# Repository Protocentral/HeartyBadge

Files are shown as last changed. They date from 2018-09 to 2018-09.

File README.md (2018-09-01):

# ProtoCentral HeartyBadge

HeartyBadge is simply our popular HeartyPatch single-lead ECG & Heart-rate variability (HRV) monitoring device made into a badge in time for DEFCON 26, where I presented about our HealthyPi open-source patient monitor. We think of HeartyBadge as a ECG and HRV development board, on a badge. 

The following are the main features of the HeartyBadge: 
* Single-lead ECG monitoring with the MAX30003 
* 2 gold-plated pads on the PCB act as electrodes 
* ESP32 with PCB antenna supporting Bluetooth & Wi-Fi 
* 144 APA102 RGB addressable LEDs (most of them in a matrix) 
* On-board Li-Ion battery with charging 
* USB for charging, code upload as well as debugging 

More information is available on our Hackaday project page at: https://hackaday.io/project/160846-heartybadge

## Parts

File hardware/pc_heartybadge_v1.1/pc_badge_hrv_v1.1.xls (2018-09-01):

pc_badge_hrv_v1.1
Qty | Value | Parts | Package
5 | 0.1uF | C2, C6, C7, C8, C11 | C0402
2 | 0.1uF | C60, C62 | C0402
1 | 1.0uF | C63 | C0402
1 | 1000pF | C76 | C0402
2 | 100nF | C81, C82 | _0402
84 |  | C1, C3, C4, C5, C9, C10, C12, C14, C16, C17, C18, C19, C21, C22, C23, C24, C25, C26, C27, C28, C29, C30, C31, C32, C33, C34, C35, C36, C37, C38, C39, C40, C41, C42, C43, C44, C45, C46, C47, C50, C51, C52, C53, C54, C55, C56, C59, C66, C83, C84, C85, C86, C87, C88, C89, C90, C91, C92, C93, C94, C95, C96, C97, C98, C99, C100, C101, C102, C103, C104, C105, C106, C107, C108, C109, C110, C111, C112, C113, C114, C115, C116, C117, C118 | C0402K
2 | 10pF | C74, C75 | C0402
2 | 10uF | C13, C15 | C0603
6 | 10uF | C70, C71, C77, C79, C121, C122 | C0402
1 | 10uF | C61 | C0805
2 | 15pF | C57, C58 | C0603
1 | 1nF | C68 | C0402
3 | 1u | C72, C119, C120 | C0402
4 | 1uF | C20, C69, C73, C78 | C0402
1 | 1uF | C80 | C0402
1 | 2.2uF | C67 | C0402
1 | 2.4pF | C48 | C0603
2 | 4.7u | C64, C65 | C0805
1 | 5.6pF | C49 | C0603
2 | 10K | R19, R23 | R0402
3 | 10K | R1, R4, R7 | 0402-RES
2 | 10k | R9, R10 | R0603
4 | 10k | R8, R11, R25, R26 | R0603
1 | 10k | R20 | R0402
2 | 1K | R12, R13 | R0402
1 | 1k | R17 | R0402
2 | 27R | R14, R15 | R0402
3 | 330R | R2, R5, R16 | R0402
2 | 49.9K | R3, R6 | 0402-RES
1 | 2.5A/30V | Q2 | SOT23-3
1 | 2.7nH | L1 | L0603
1 | 32.768kHz | Y1 | CRYSTAL-SMD-3.2X1.5MM
1 | AP2112K-1.8V | U9 | SOT23-5
1 | AP2112K-3.3V | U8 | SOT23-5
1 | AP2281 | U$2 | SOT26
117 | APA1022020 | U$9, U$10, U$11, U$12, U$13, U$14, U$15, U$18, U$19, U$20, U$21, U$22, U$24, U$25, U$27, U$28, U$29, U$30, U$31, U$32, U$33, U$34, U$35, U$36, U$37, U$38, U$39, U$40, U$41, U$42, U$43, U$44, U$45, U$46, U$47, U$48, U$49, U$50, U$51, U$52, U$53, U$54, U$55, U$56, U$57, U$58, U$59, U$60, U$61, U$62, U$63, U$64, U$65, U$66, U$67, U$68, U$69, U$70, U$71, U$72, U$73, U$74, U$75, U$76, U$77, U$78, U$79, U$80, U$81, U$82, U$83, U$84, U$85, U$86, U$87, U$88, U$89, U$90, U$91, U$92, U$93, U$94, U$95, U$96, U$97, U$98, U$99, U$100, U$101, U$102, U$103, U$104, U$106, U$107, U$108, U$109, U$110, U$111, U$112, U$113, U$114, U$115, U$116, U$117, U$118, U$119, U$120, U$121, U$122, U$123, U$124, U$125, U$126, U$127, U$128, U$129, U$130 | APA102_2020
1 | BAT20J | D1 | SOD-323
1 | CY8C29666_QFN48 | IC1 | QFN48
1 | DNP | R18 | R0402
1 | FTS31XS-U | U1 | SSOP20_L
1 | KMR2 | SW2 | BTN_KMR2_4.6X2.8
1 | LSM6DS3 | U2 | LGA14L
1 | MAX30003CTI+ | U$131 | QFN-28
1 | MBT3904DW1T1 | Q1 | SC70-6
1 | MCP73831 | U3 | SOT23-5
1 | MICRO-B | JP7 | MICRO-B
1 | PCM12SMTR | S2 | SWITCH-SPST-SMD-A
1 | RED | CHG2 | CHIPLED_0603
1 | SIT1533 | U$134 | SIT1533

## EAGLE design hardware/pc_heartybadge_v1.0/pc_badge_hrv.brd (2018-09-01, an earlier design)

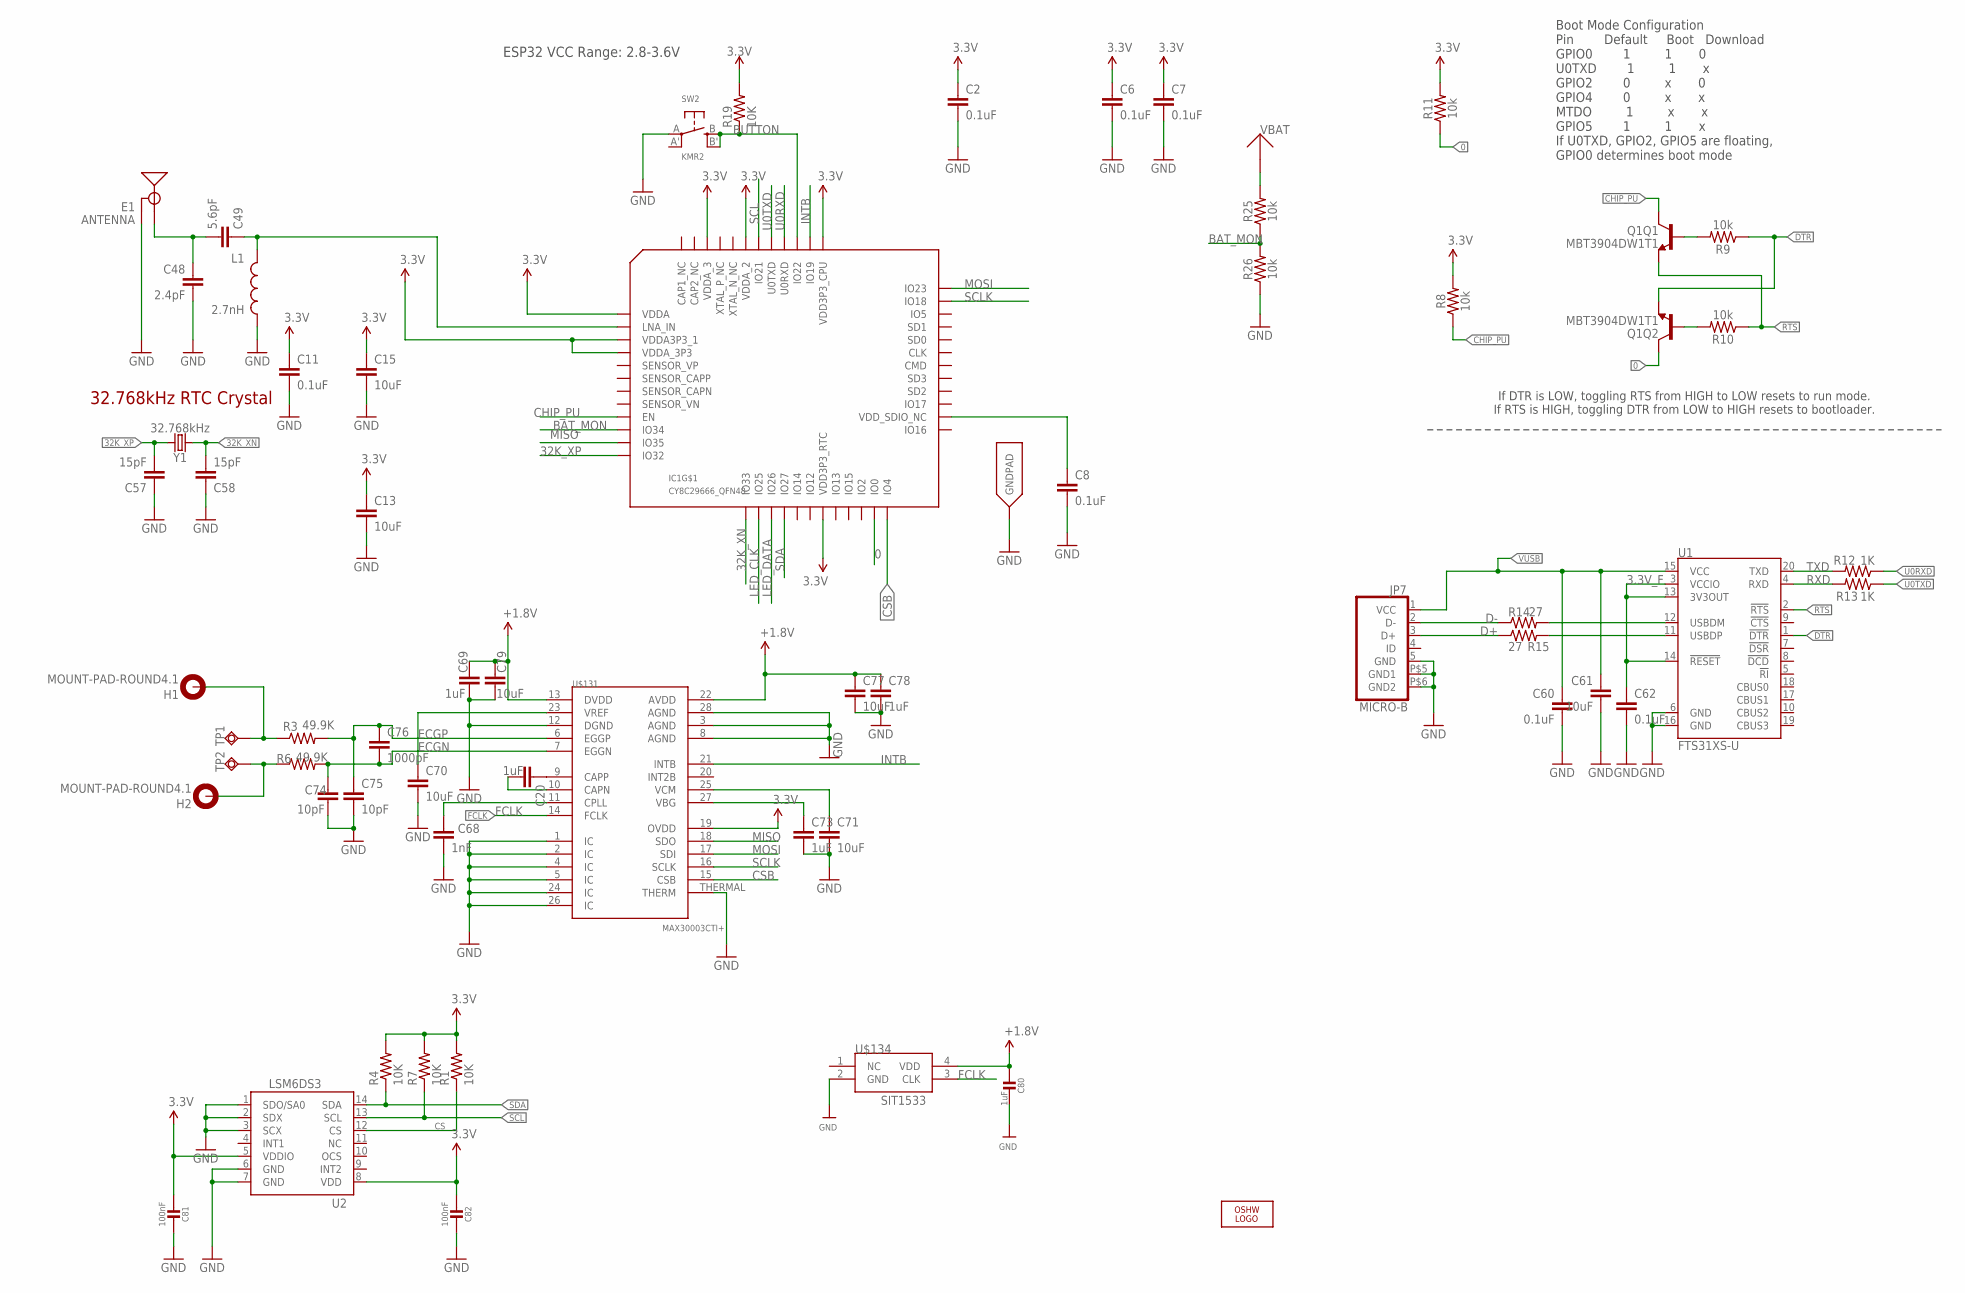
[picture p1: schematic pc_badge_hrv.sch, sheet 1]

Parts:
C2, C6, C7, C8, C11: 0.1uF; 0402
C13, C15: 10uF; 0603
C20, C69, C73, C78: 1uF; C0402
C48: 2.4pF; 0603
C49: 5.6pF; 0603
C57, C58: 15pF; 0603
C60, C62: 0.1uF; C0402
C61: 10uF; C0805
C68: 1nF; C0402
C70, C71, C77, C79: 10uF; C0402
C74, C75: 10pF; C0402
C76: 1000pF; C0402
C80: 1uF; _0402
C81, C82: 100nF; _0402
E1: ANTENNA; TRACE_ANTENNA_2.4GHZ_25.7MM_TUNED
H1, H2: MOUNT-PAD-ROUND4.1; 4,1-PAD
IC1: CY8C29666_QFN48; QFN48
JP7: MICRO-B
L1: 2.7nH; 0603
LOGO3: OSHW_LOGO_FILLX0200-NT; OSHW_FILLX200_NOTEXT
Q1: MBT3904DW1T1; SC70-6
R1, R4, R7: 10K; 0402-RES
R3, R6: 49.9K; 0402-RES
R8, R9, R10, R11, R25, R26: 10k; 0603
R12, R13: 1K; R0402
R14, R15: 27; R0402
R19: 10K; R0402
SW2: KMR2; BTN_KMR2_4.6X2.8
TP1, TP2: TPSQTP11R; TP11R
U1: FTS31XS-U; SSOP20_L
U2: LSM6DS3; LGA14L
U$131: MAX30003CTI+; QFN-28
U$134: SIT1533
Y1: 32.768kHz; CRYSTAL-SMD-3.2X1.5MM

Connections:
0: IC1.23 (IO0), Q1.6 (C), R11.1
3.3V: C2.1, C6.1, C7.1, C11.1, C13.1, C15.1, C81.1, C82.1, IC1.1 (VDDA), IC1.3 (VDDA3P3_1), IC1.4 (VDDA_3P3), IC1.19 (VDD3P3_RTC), IC1.37 (VDD3P3_CPU), IC1.43 (VDDA_2), IC1.46 (VDDA_3), R1.2, R4.2, R7.2, R8.2, R11.2, R19.2, U2.5 (VDDIO), U2.8 (VDD), U$131.19 (OVDD); also elsewhere on the board
3.3V_F: C62.1, U1.3 (VCCIO), U1.13 (3V3OUT), U1.14 (!RESET)
32K_XN: C58.2, IC1.13 (IO33), Y1.P$2 (2)
32K_XP: C57.2, IC1.12 (IO32), Y1.P$1 (1)
+1.8V: C69.1, C77.1, C78.1, C79.1, C80.1, U$131.13 (DVDD), U$131.22 (AVDD), U$134.4 (VDD)
BAT_MON: IC1.10 (IO34), R25.1, R26.2
BUTTON: IC1.39 (IO22), R19.1, SW2.B (S), SW2.B' (S1)
CHIP_PU: IC1.9 (EN), Q1.3 (C), R8.1
CS: R1.1, U2.12 (CS)
CSB: IC1.24 (IO4), U$131.15 (CSB)
D+: JP7.3 (D+), R15.1
D-: JP7.2 (D-), R14.1
DTR: Q1.1 (E), R9.1, U1.1 (!DTR)
ECGN: C74.1, C76.2, R6.2, U$131.7 (EGGN)
ECGP: C75.1, C76.1, R3.2, U$131.6 (EGGP)
ECG_N: H2.B4,1, R6.1, TP2.TP
ECG_P: H1.B4,1, R3.1, TP1.TP
FCLK: U$131.14 (FCLK), U$134.3 (CLK)
GND: C2.2, C6.2, C7.2, C8.2, C11.2, C13.2, C15.2, C48.2, C57.1, C58.1, C60.2, C61.2, C62.2, C68.2, C69.2, C70.2, C71.2, C73.2, C74.2, C75.2, C77.2, C78.2, C79.2, C80.2, C81.2, C82.2, E1.GND, E1.GND2 (GND), IC1.EXP (GNDPAD), JP7.5 (GND), JP7.P$5 (GND1), JP7.P$6 (GND2), L1.2, R26.1, SW2.A, U1.6 (GND), U1.16 (GND), U2.1 (SDO/SA0), U2.2 (SDX), U2.3 (SCX), U2.6 (GND), U2.7 (GND), U$131.1 (IC), U$131.2 (IC), U$131.3 (AGND), U$131.4 (IC), U$131.5 (IC), U$131.8 (AGND), U$131.12 (DGND), U$131.24 (IC), U$131.26 (IC), U$131.28 (AGND), U$131.THERMAL (THERM), U$134.2 (GND); also elsewhere on the board
INTB: IC1.38 (IO19), U$131.21 (INTB)
IO12: IC1.18 (IO12)
LED_CLK: IC1.14 (IO25); also elsewhere on the board
LED_DATA: IC1.15 (IO26); also elsewhere on the board
LNA_IN: C49.1, IC1.2 (LNA_IN), L1.1
MISO: IC1.11 (IO35), U$131.18 (SDO)
MOSI: IC1.36 (IO23), U$131.17 (SDI)
unnamed: C8.1, IC1.26 (VDD_SDIO_NC)
unnamed: Q1.5 (B), R9.2
unnamed: Q1.2 (B), R10.2
unnamed: R14.2, U1.12 (USBDM)
unnamed: R15.2, U1.11 (USBDP)
unnamed: C68.1, U$131.11 (CPLL)
unnamed: C20.1, U$131.9 (CAPP)
unnamed: C20.2, U$131.10 (CAPN)
unnamed: C70.1, U$131.23 (VREF)
unnamed: C71.1, U$131.25 (VCM)
unnamed: C73.1, U$131.27 (VBG)
RTS: Q1.4 (E), R10.1, U1.2 (!RTS)
RXD: R13.2, U1.4 (RXD)
SCL: IC1.42 (IO21), R7.1, U2.13 (SCL)
SCLK: IC1.35 (IO18), U$131.16 (SCLK)
SDA: IC1.16 (IO27), R4.1, U2.14 (SDA)
SENSOR_CAPN: IC1.7 (SENSOR_CAPN)
TRACE_ANT2: C48.1, C49.2, E1.ANT (SIGNAL)
TXD: R12.2, U1.20 (TXD)
U0RXD: IC1.40 (U0RXD), R12.1
U0TXD: IC1.41 (U0TXD), R13.1
VBAT: R25.2; also elsewhere on the board
VUSB: C60.1, C61.1, JP7.1 (VCC), U1.15 (VCC); also elsewhere on the board

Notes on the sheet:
Boot Mode Configuration Pin Default Boot Download GPIO0 1 1 0 U0TXD 1 1 x GPIO2 0 x 0 GPIO4 0 x x MTDO 1 x x GPIO5 1 1 x If U0TXD, GPIO2, GPIO5 are floating, GPIO0 determines boot mode
32.768kHz RTC Crystal
ESP32 VCC Range: 2.8-3.6V
If DTR is LOW, toggling RTS from HIGH to LOW resets to run mode. If RTS is HIGH, toggling DTR from LOW to HIGH resets to bootloader.

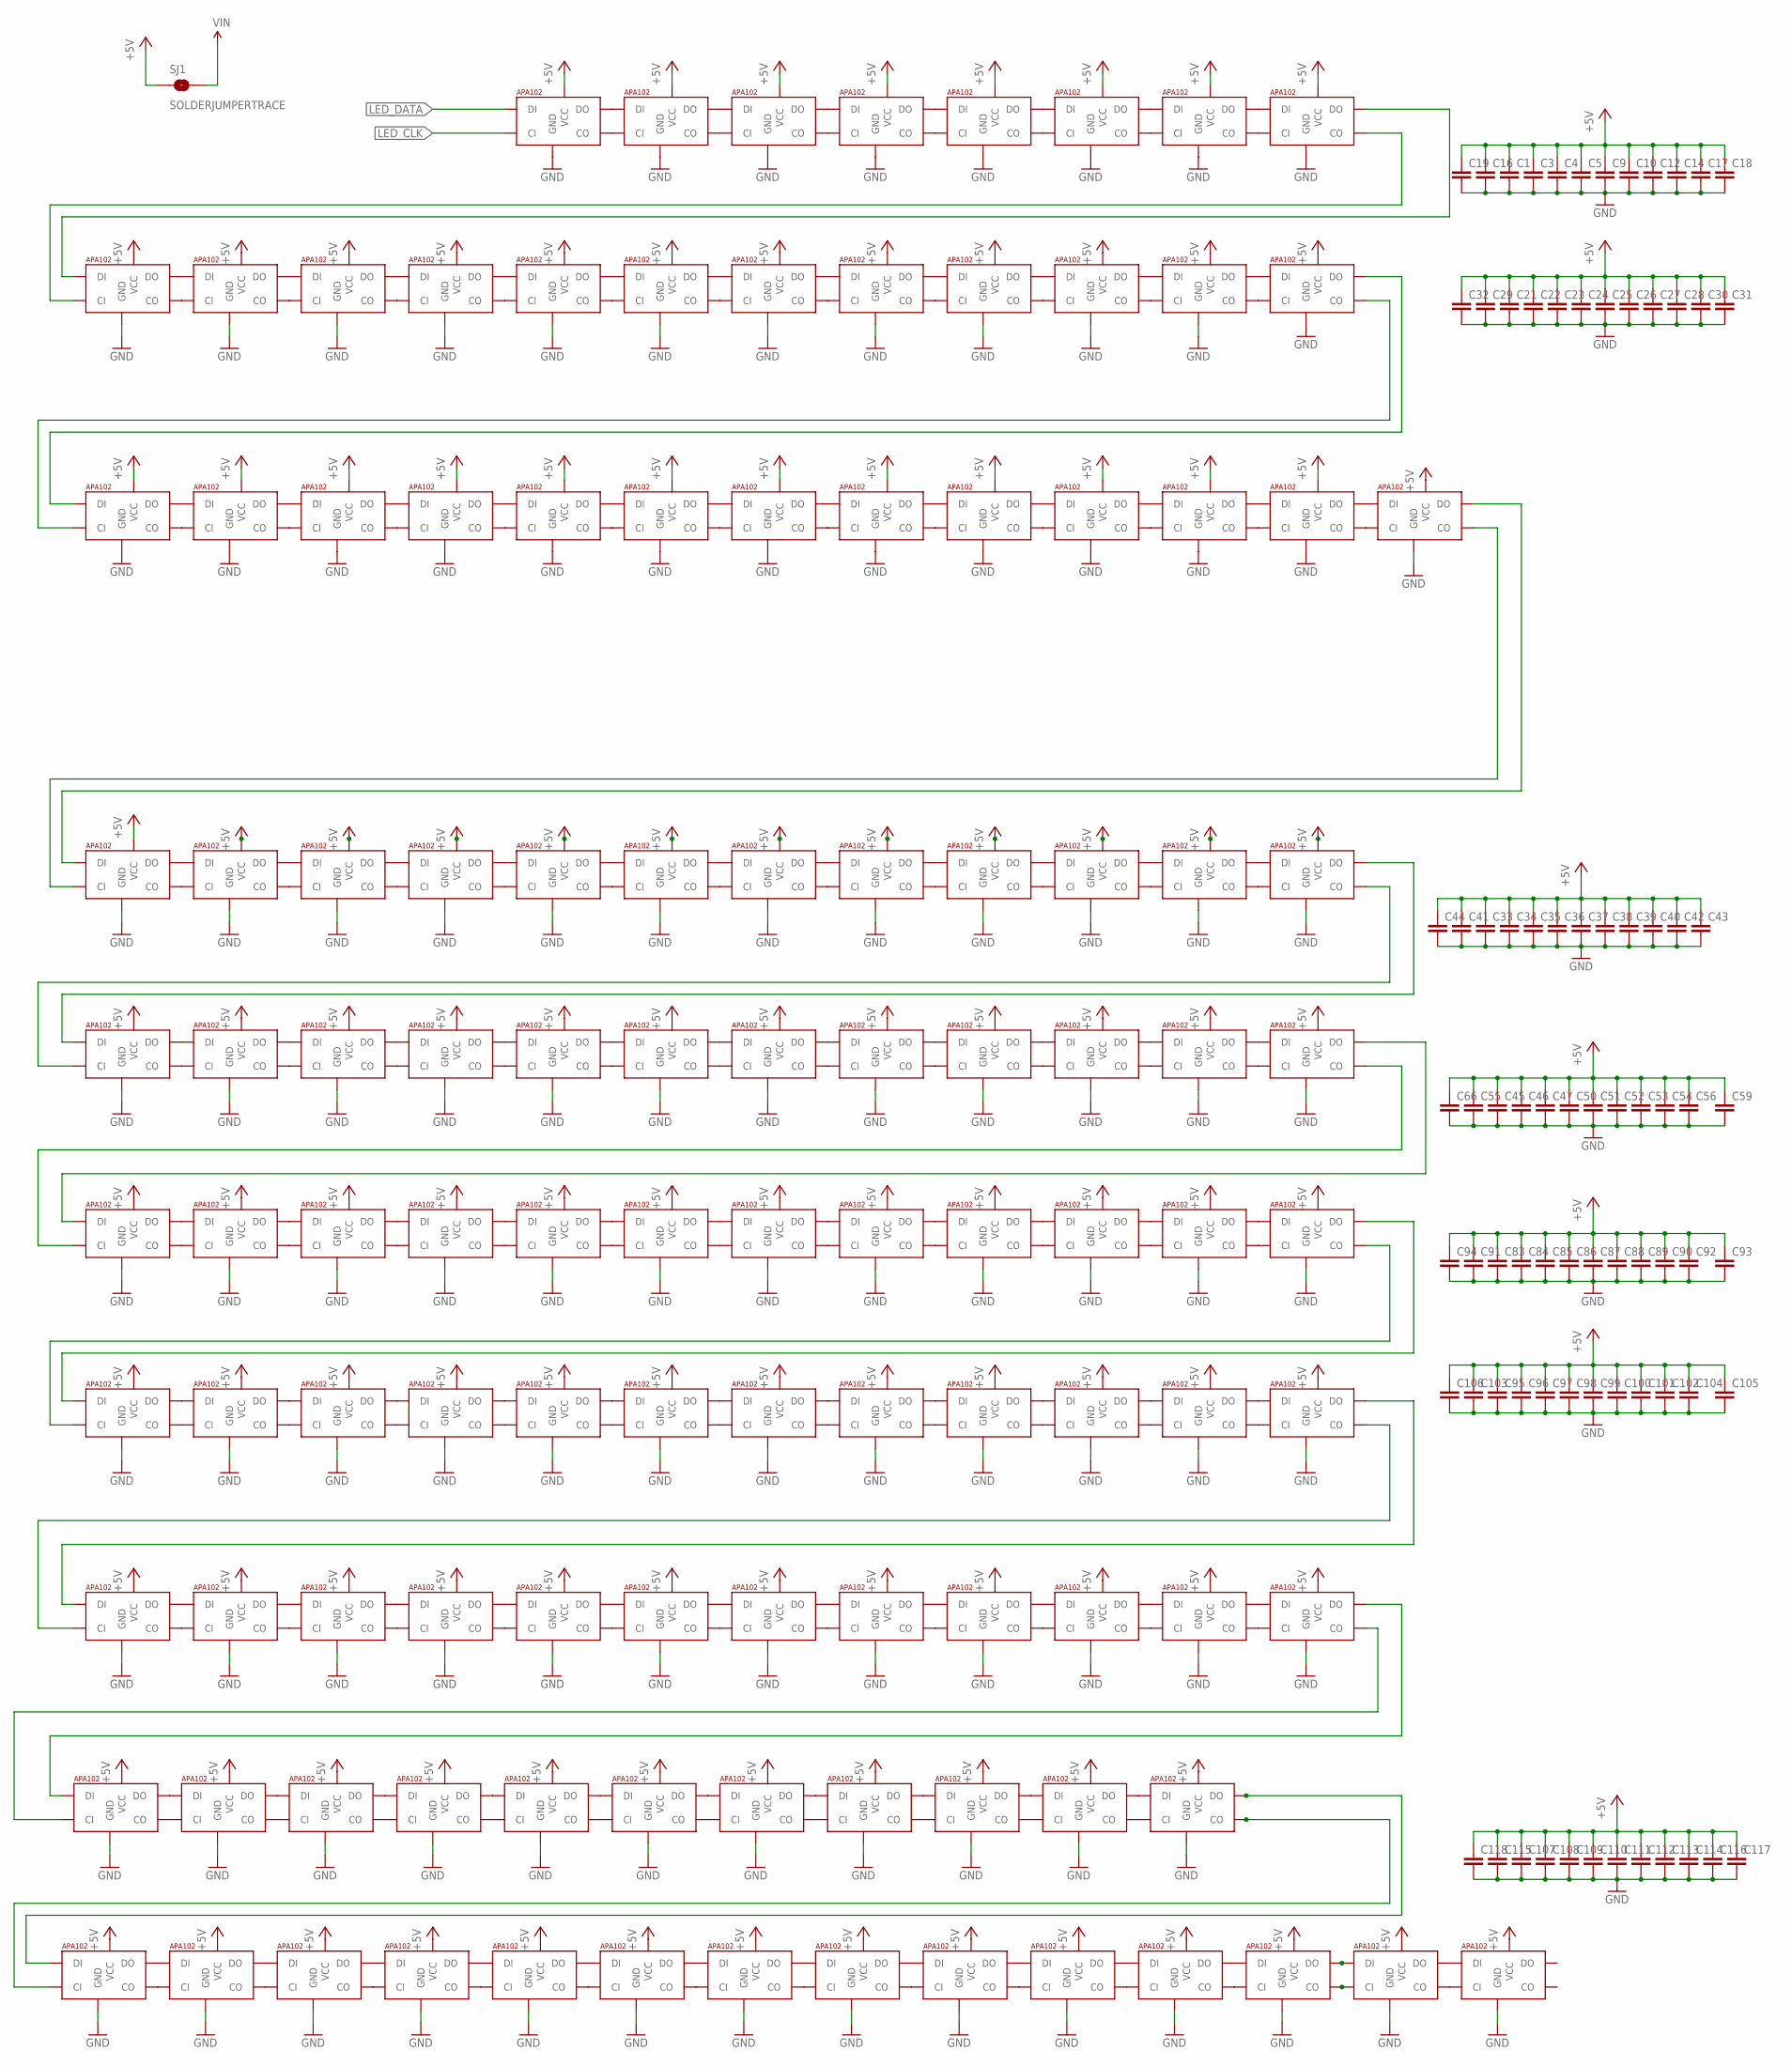
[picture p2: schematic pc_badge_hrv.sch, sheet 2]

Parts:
C1, C3, C4, C5, C9, C10, C12, C14, C16, C17, C18, C19, C21, C22, C23, C24, C25, C26, C27, C28, C29, C30, C31, C32, C33, C34, C35, C36, C37, C38, C39, C40, C41, C42, C43, C44, C45, C46, C47, C50, C51, C52, C53, C54, C55, C56, C59, C66, C83, C84, C85, C86, C87, C88, C89, C90, C91, C92, C93, C94, C95, C96, C97, C98, C99, C100, C101, C102, C103, C104, C105, C106, C107, C108, C109, C110, C111, C112, C113, C114, C115, C116, C117, C118: C-EUC0402K; C0402K
SJ1: SOLDERJUMPERTRACE; SJ_2S-TRACE
U$9, U$10, U$11, U$12, U$13, U$14, U$15, U$18, U$19, U$20, U$21, U$22, U$24, U$25, U$27, U$28, U$29, U$30, U$31, U$32, U$33, U$34, U$35, U$36, U$37, U$38, U$39, U$40, U$41, U$42, U$43, U$44, U$45, U$46, U$47, U$48, U$49, U$50, U$51, U$52, U$53, U$54, U$55, U$56, U$57, U$58, U$59, U$60, U$61, U$62, U$63, U$64, U$65, U$66, U$67, U$68, U$69, U$70, U$71, U$72, U$73, U$74, U$75, U$76, U$77, U$78, U$79, U$80, U$81, U$82, U$83, U$84, U$85, U$86, U$87, U$88, U$89, U$90, U$91, U$92, U$93, U$94, U$95, U$96, U$97, U$98, U$99, U$100, U$101, U$102, U$103, U$104, U$105, U$106, U$107, U$108, U$109, U$110, U$111, U$112, U$113, U$114, U$115, U$116, U$117, U$118, U$119, U$120, U$121, U$122, U$123, U$124, U$125, U$126, U$127, U$128, U$129, U$130: APA1022020; APA102_2020

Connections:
+5V: C1.1, C3.1, C4.1, C5.1, C9.1, C10.1, C12.1, C14.1, C16.1, C17.1, C18.1, C19.1, C21.1, C22.1, C23.1, C24.1, C25.1, C26.1, C27.1, C28.1, C29.1, C30.1, C31.1, C32.1, C33.1, C34.1, C35.1, C36.1, C37.1, C38.1, C39.1, C40.1, C41.1, C42.1, C43.1, C44.1, C45.1, C46.1, C47.1, C50.1, C51.1, C52.1, C53.1, C54.1, C55.1, C56.1, C59.1, C66.1, C83.1, C84.1, C85.1, C86.1, C87.1, C88.1, C89.1, C90.1, C91.1, C92.1, C93.1, C94.1, C95.1, C96.1, C97.1, C98.1, C99.1, C100.1, C101.1, C102.1, C103.1, C104.1, C105.1, C106.1, C107.1, C108.1, C109.1, C110.1, C111.1, C112.1, C113.1, C114.1, C115.1, C116.1, C117.1, C118.1, SJ1.1, U$9.V_CC (VCC), U$10.V_CC (VCC), U$11.V_CC (VCC), U$12.V_CC (VCC), U$13.V_CC (VCC), U$14.V_CC (VCC), U$15.V_CC (VCC), U$18.V_CC (VCC), U$19.V_CC (VCC), U$20.V_CC (VCC), U$21.V_CC (VCC), U$22.V_CC (VCC), U$24.V_CC (VCC), U$25.V_CC (VCC), U$27.V_CC (VCC), U$28.V_CC (VCC), U$29.V_CC (VCC), U$30.V_CC (VCC), U$31.V_CC (VCC), U$32.V_CC (VCC), U$33.V_CC (VCC), U$34.V_CC (VCC), U$35.V_CC (VCC), U$36.V_CC (VCC), U$37.V_CC (VCC), U$38.V_CC (VCC), U$39.V_CC (VCC), U$40.V_CC (VCC), U$41.V_CC (VCC), U$42.V_CC (VCC), U$43.V_CC (VCC), U$44.V_CC (VCC), U$45.V_CC (VCC), U$46.V_CC (VCC), U$47.V_CC (VCC), U$48.V_CC (VCC), U$49.V_CC (VCC), U$50.V_CC (VCC), U$51.V_CC (VCC), U$52.V_CC (VCC), U$53.V_CC (VCC), U$54.V_CC (VCC), U$55.V_CC (VCC), U$56.V_CC (VCC), U$57.V_CC (VCC), U$58.V_CC (VCC), U$59.V_CC (VCC), U$60.V_CC (VCC), U$61.V_CC (VCC), U$62.V_CC (VCC), U$63.V_CC (VCC), U$64.V_CC (VCC), U$65.V_CC (VCC), U$66.V_CC (VCC), U$67.V_CC (VCC), U$68.V_CC (VCC), U$69.V_CC (VCC), U$70.V_CC (VCC), U$71.V_CC (VCC), U$72.V_CC (VCC), U$73.V_CC (VCC), U$74.V_CC (VCC), U$75.V_CC (VCC), U$76.V_CC (VCC), U$77.V_CC (VCC), U$78.V_CC (VCC), U$79.V_CC (VCC), U$80.V_CC (VCC), U$81.V_CC (VCC), U$82.V_CC (VCC), U$83.V_CC (VCC), U$84.V_CC (VCC), U$85.V_CC (VCC), U$86.V_CC (VCC), U$87.V_CC (VCC), U$88.V_CC (VCC), U$89.V_CC (VCC), U$90.V_CC (VCC), U$91.V_CC (VCC), U$92.V_CC (VCC), U$93.V_CC (VCC), U$94.V_CC (VCC), U$95.V_CC (VCC), U$96.V_CC (VCC), U$97.V_CC (VCC), U$98.V_CC (VCC), U$99.V_CC (VCC), U$100.V_CC (VCC), U$101.V_CC (VCC), U$102.V_CC (VCC), U$103.V_CC (VCC), U$104.V_CC (VCC), U$105.V_CC (VCC), U$106.V_CC (VCC), U$107.V_CC (VCC), U$108.V_CC (VCC), U$109.V_CC (VCC), U$110.V_CC (VCC), U$111.V_CC (VCC), U$112.V_CC (VCC), U$113.V_CC (VCC), U$114.V_CC (VCC), U$115.V_CC (VCC), U$116.V_CC (VCC), U$117.V_CC (VCC), U$118.V_CC (VCC), U$119.V_CC (VCC), U$120.V_CC (VCC), U$121.V_CC (VCC), U$122.V_CC (VCC), U$123.V_CC (VCC), U$124.V_CC (VCC), U$125.V_CC (VCC), U$126.V_CC (VCC), U$127.V_CC (VCC), U$128.V_CC (VCC), U$129.V_CC (VCC), U$130.V_CC (VCC)
GND: C1.2, C3.2, C4.2, C5.2, C9.2, C10.2, C12.2, C14.2, C16.2, C17.2, C18.2, C19.2, C21.2, C22.2, C23.2, C24.2, C25.2, C26.2, C27.2, C28.2, C29.2, C30.2, C31.2, C32.2, C33.2, C34.2, C35.2, C36.2, C37.2, C38.2, C39.2, C40.2, C41.2, C42.2, C43.2, C44.2, C45.2, C46.2, C47.2, C50.2, C51.2, C52.2, C53.2, C54.2, C55.2, C56.2, C59.2, C66.2, C83.2, C84.2, C85.2, C86.2, C87.2, C88.2, C89.2, C90.2, C91.2, C92.2, C93.2, C94.2, C95.2, C96.2, C97.2, C98.2, C99.2, C100.2, C101.2, C102.2, C103.2, C104.2, C105.2, C106.2, C107.2, C108.2, C109.2, C110.2, C111.2, C112.2, C113.2, C114.2, C115.2, C116.2, C117.2, C118.2, U$9.GND, U$10.GND, U$11.GND, U$12.GND, U$13.GND, U$14.GND, U$15.GND, U$18.GND, U$19.GND, U$20.GND, U$21.GND, U$22.GND, U$24.GND, U$25.GND, U$27.GND, U$28.GND, U$29.GND, U$30.GND, U$31.GND, U$32.GND, U$33.GND, U$34.GND, U$35.GND, U$36.GND, U$37.GND, U$38.GND, U$39.GND, U$40.GND, U$41.GND, U$42.GND, U$43.GND, U$44.GND, U$45.GND, U$46.GND, U$47.GND, U$48.GND, U$49.GND, U$50.GND, U$51.GND, U$52.GND, U$53.GND, U$54.GND, U$55.GND, U$56.GND, U$57.GND, U$58.GND, U$59.GND, U$60.GND, U$61.GND, U$62.GND, U$63.GND, U$64.GND, U$65.GND, U$66.GND, U$67.GND, U$68.GND, U$69.GND, U$70.GND, U$71.GND, U$72.GND, U$73.GND, U$74.GND, U$75.GND, U$76.GND, U$77.GND, U$78.GND, U$79.GND, U$80.GND, U$81.GND, U$82.GND, U$83.GND, U$84.GND, U$85.GND, U$86.GND, U$87.GND, U$88.GND, U$89.GND, U$90.GND, U$91.GND, U$92.GND, U$93.GND, U$94.GND, U$95.GND, U$96.GND, U$97.GND, U$98.GND, U$99.GND, U$100.GND, U$101.GND, U$102.GND, U$103.GND, U$104.GND, U$105.GND, U$106.GND, U$107.GND, U$108.GND, U$109.GND, U$110.GND, U$111.GND, U$112.GND, U$113.GND, U$114.GND, U$115.GND, U$116.GND, U$117.GND, U$118.GND, U$119.GND, U$120.GND, U$121.GND, U$122.GND, U$123.GND, U$124.GND, U$125.GND, U$126.GND, U$127.GND, U$128.GND, U$129.GND, U$130.GND; also elsewhere on the board
LED_CLK: U$9.C_IN (CI); also elsewhere on the board
LED_DATA: U$9.D_IN (DI); also elsewhere on the board
unnamed: U$104.D_OUT (DO), U$119.D_IN (DI)
unnamed: U$104.CL_OUT (CO), U$119.C_IN (CI)
unnamed: U$9.D_OUT (DO), U$10.D_IN (DI)
unnamed: U$9.CL_OUT (CO), U$10.C_IN (CI)
unnamed: U$11.D_OUT (DO), U$12.D_IN (DI)
unnamed: U$11.CL_OUT (CO), U$12.C_IN (CI)
unnamed: U$12.D_OUT (DO), U$13.D_IN (DI)
unnamed: U$12.CL_OUT (CO), U$13.C_IN (CI)
unnamed: U$13.D_OUT (DO), U$14.D_IN (DI)
unnamed: U$13.CL_OUT (CO), U$14.C_IN (CI)
unnamed: U$14.D_OUT (DO), U$15.D_IN (DI)
unnamed: U$14.CL_OUT (CO), U$15.C_IN (CI)
unnamed: U$15.D_OUT (DO), U$18.D_IN (DI)
unnamed: U$15.CL_OUT (CO), U$18.C_IN (CI)
unnamed: U$10.D_OUT (DO), U$11.D_IN (DI)
unnamed: U$10.CL_OUT (CO), U$11.C_IN (CI)
unnamed: U$19.D_OUT (DO), U$20.D_IN (DI)
unnamed: U$19.CL_OUT (CO), U$20.C_IN (CI)
unnamed: U$20.D_OUT (DO), U$21.D_IN (DI)
unnamed: U$20.CL_OUT (CO), U$21.C_IN (CI)
unnamed: U$21.D_OUT (DO), U$22.D_IN (DI)
unnamed: U$21.CL_OUT (CO), U$22.C_IN (CI)
unnamed: U$22.D_OUT (DO), U$24.D_IN (DI)
unnamed: U$22.CL_OUT (CO), U$24.C_IN (CI)
unnamed: U$24.D_OUT (DO), U$25.D_IN (DI)
unnamed: U$24.CL_OUT (CO), U$25.C_IN (CI)
unnamed: U$27.D_OUT (DO), U$28.D_IN (DI)
unnamed: U$27.CL_OUT (CO), U$28.C_IN (CI)
unnamed: U$28.D_OUT (DO), U$29.D_IN (DI)
unnamed: U$28.CL_OUT (CO), U$29.C_IN (CI)
unnamed: U$29.D_OUT (DO), U$30.D_IN (DI)
unnamed: U$29.CL_OUT (CO), U$30.C_IN (CI)
unnamed: U$30.D_OUT (DO), U$31.D_IN (DI)
unnamed: U$30.CL_OUT (CO), U$31.C_IN (CI)
unnamed: U$119.D_OUT (DO), U$120.D_IN (DI)
unnamed: U$119.CL_OUT (CO), U$120.C_IN (CI)
unnamed: U$25.D_OUT (DO), U$27.D_IN (DI)
unnamed: U$25.CL_OUT (CO), U$27.C_IN (CI)
unnamed: U$33.D_OUT (DO), U$34.D_IN (DI)
unnamed: U$33.CL_OUT (CO), U$34.C_IN (CI)
unnamed: U$34.D_OUT (DO), U$35.D_IN (DI)
unnamed: U$34.CL_OUT (CO), U$35.C_IN (CI)
unnamed: U$35.D_OUT (DO), U$36.D_IN (DI)
unnamed: U$35.CL_OUT (CO), U$36.C_IN (CI)
unnamed: U$36.D_OUT (DO), U$37.D_IN (DI)
unnamed: U$36.CL_OUT (CO), U$37.C_IN (CI)
unnamed: U$37.D_OUT (DO), U$38.D_IN (DI)
unnamed: U$37.CL_OUT (CO), U$38.C_IN (CI)
unnamed: U$39.D_OUT (DO), U$40.D_IN (DI)
unnamed: U$39.CL_OUT (CO), U$40.C_IN (CI)
unnamed: U$40.D_OUT (DO), U$41.D_IN (DI)
unnamed: U$40.CL_OUT (CO), U$41.C_IN (CI)
unnamed: U$41.D_OUT (DO), U$42.D_IN (DI)
unnamed: U$41.CL_OUT (CO), U$42.C_IN (CI)
unnamed: U$42.D_OUT (DO), U$43.D_IN (DI)
unnamed: U$42.CL_OUT (CO), U$43.C_IN (CI)
unnamed: U$43.D_OUT (DO), U$44.D_IN (DI)
unnamed: U$43.CL_OUT (CO), U$44.C_IN (CI)
unnamed: U$38.D_OUT (DO), U$39.D_IN (DI)
unnamed: U$38.CL_OUT (CO), U$39.C_IN (CI)
unnamed: U$45.D_OUT (DO), U$46.D_IN (DI)
unnamed: U$45.CL_OUT (CO), U$46.C_IN (CI)
unnamed: U$46.D_OUT (DO), U$47.D_IN (DI)
unnamed: U$46.CL_OUT (CO), U$47.C_IN (CI)
unnamed: U$47.D_OUT (DO), U$48.D_IN (DI)
unnamed: U$47.CL_OUT (CO), U$48.C_IN (CI)
unnamed: U$48.D_OUT (DO), U$49.D_IN (DI)
unnamed: U$48.CL_OUT (CO), U$49.C_IN (CI)
unnamed: U$49.D_OUT (DO), U$50.D_IN (DI)
unnamed: U$49.CL_OUT (CO), U$50.C_IN (CI)
unnamed: U$51.D_OUT (DO), U$52.D_IN (DI)
unnamed: U$51.CL_OUT (CO), U$52.C_IN (CI)
unnamed: U$52.D_OUT (DO), U$53.D_IN (DI)
unnamed: U$52.CL_OUT (CO), U$53.C_IN (CI)
unnamed: U$53.D_OUT (DO), U$54.D_IN (DI)
unnamed: U$53.CL_OUT (CO), U$54.C_IN (CI)
unnamed: U$54.D_OUT (DO), U$55.D_IN (DI)
unnamed: U$54.CL_OUT (CO), U$55.C_IN (CI)
unnamed: U$55.D_OUT (DO), U$56.D_IN (DI)
unnamed: U$55.CL_OUT (CO), U$56.C_IN (CI)
unnamed: U$50.D_OUT (DO), U$51.D_IN (DI)
unnamed: U$50.CL_OUT (CO), U$51.C_IN (CI)
unnamed: U$18.D_OUT (DO), U$19.D_IN (DI)
unnamed: U$18.CL_OUT (CO), U$19.C_IN (CI)
unnamed: U$32.D_OUT (DO), U$33.D_IN (DI)
unnamed: U$32.CL_OUT (CO), U$33.C_IN (CI)
unnamed: U$44.CL_OUT (CO), U$45.C_IN (CI)
unnamed: U$44.D_OUT (DO), U$45.D_IN (DI)
unnamed: U$57.D_OUT (DO), U$58.D_IN (DI)
unnamed: U$57.CL_OUT (CO), U$58.C_IN (CI)
unnamed: U$58.D_OUT (DO), U$59.D_IN (DI)
unnamed: U$58.CL_OUT (CO), U$59.C_IN (CI)
unnamed: U$59.D_OUT (DO), U$60.D_IN (DI)
unnamed: U$59.CL_OUT (CO), U$60.C_IN (CI)
unnamed: U$60.D_OUT (DO), U$61.D_IN (DI)
unnamed: U$60.CL_OUT (CO), U$61.C_IN (CI)
unnamed: U$61.D_OUT (DO), U$62.D_IN (DI)
unnamed: U$61.CL_OUT (CO), U$62.C_IN (CI)
unnamed: U$63.D_OUT (DO), U$64.D_IN (DI)
unnamed: U$63.CL_OUT (CO), U$64.C_IN (CI)
unnamed: U$64.D_OUT (DO), U$65.D_IN (DI)
unnamed: U$64.CL_OUT (CO), U$65.C_IN (CI)
unnamed: U$65.D_OUT (DO), U$66.D_IN (DI)
unnamed: U$65.CL_OUT (CO), U$66.C_IN (CI)
unnamed: U$66.D_OUT (DO), U$67.D_IN (DI)
unnamed: U$66.CL_OUT (CO), U$67.C_IN (CI)
unnamed: U$67.D_OUT (DO), U$68.D_IN (DI)
unnamed: U$67.CL_OUT (CO), U$68.C_IN (CI)
unnamed: U$62.D_OUT (DO), U$63.D_IN (DI)
unnamed: U$62.CL_OUT (CO), U$63.C_IN (CI)
unnamed: U$56.CL_OUT (CO), U$57.C_IN (CI)
unnamed: U$56.D_OUT (DO), U$57.D_IN (DI)
unnamed: U$69.D_OUT (DO), U$70.D_IN (DI)
unnamed: U$69.CL_OUT (CO), U$70.C_IN (CI)
unnamed: U$70.D_OUT (DO), U$71.D_IN (DI)
unnamed: U$70.CL_OUT (CO), U$71.C_IN (CI)
unnamed: U$71.D_OUT (DO), U$72.D_IN (DI)
unnamed: U$71.CL_OUT (CO), U$72.C_IN (CI)
unnamed: U$72.D_OUT (DO), U$73.D_IN (DI)
unnamed: U$72.CL_OUT (CO), U$73.C_IN (CI)
unnamed: U$73.D_OUT (DO), U$74.D_IN (DI)
unnamed: U$73.CL_OUT (CO), U$74.C_IN (CI)
unnamed: U$75.D_OUT (DO), U$76.D_IN (DI)
unnamed: U$75.CL_OUT (CO), U$76.C_IN (CI)
unnamed: U$76.D_OUT (DO), U$77.D_IN (DI)
unnamed: U$76.CL_OUT (CO), U$77.C_IN (CI)
unnamed: U$77.D_OUT (DO), U$78.D_IN (DI)
unnamed: U$77.CL_OUT (CO), U$78.C_IN (CI)
unnamed: U$78.D_OUT (DO), U$79.D_IN (DI)
unnamed: U$78.CL_OUT (CO), U$79.C_IN (CI)
unnamed: U$79.D_OUT (DO), U$80.D_IN (DI)
unnamed: U$79.CL_OUT (CO), U$80.C_IN (CI)
unnamed: U$74.D_OUT (DO), U$75.D_IN (DI)
unnamed: U$74.CL_OUT (CO), U$75.C_IN (CI)
unnamed: U$68.CL_OUT (CO), U$69.C_IN (CI)
unnamed: U$68.D_OUT (DO), U$69.D_IN (DI)
unnamed: U$81.D_OUT (DO), U$82.D_IN (DI)
unnamed: U$81.CL_OUT (CO), U$82.C_IN (CI)
unnamed: U$82.D_OUT (DO), U$83.D_IN (DI)
unnamed: U$82.CL_OUT (CO), U$83.C_IN (CI)
unnamed: U$83.D_OUT (DO), U$84.D_IN (DI)
unnamed: U$83.CL_OUT (CO), U$84.C_IN (CI)
unnamed: U$84.D_OUT (DO), U$85.D_IN (DI)
unnamed: U$84.CL_OUT (CO), U$85.C_IN (CI)
unnamed: U$85.D_OUT (DO), U$86.D_IN (DI)
unnamed: U$85.CL_OUT (CO), U$86.C_IN (CI)
unnamed: U$87.D_OUT (DO), U$88.D_IN (DI)
unnamed: U$87.CL_OUT (CO), U$88.C_IN (CI)
unnamed: U$88.D_OUT (DO), U$89.D_IN (DI)
unnamed: U$88.CL_OUT (CO), U$89.C_IN (CI)
unnamed: U$89.D_OUT (DO), U$90.D_IN (DI)
unnamed: U$89.CL_OUT (CO), U$90.C_IN (CI)
unnamed: U$90.D_OUT (DO), U$91.D_IN (DI)
unnamed: U$90.CL_OUT (CO), U$91.C_IN (CI)
unnamed: U$91.D_OUT (DO), U$92.D_IN (DI)
unnamed: U$91.CL_OUT (CO), U$92.C_IN (CI)
unnamed: U$86.D_OUT (DO), U$87.D_IN (DI)
unnamed: U$86.CL_OUT (CO), U$87.C_IN (CI)
unnamed: U$80.CL_OUT (CO), U$81.C_IN (CI)
unnamed: U$80.D_OUT (DO), U$81.D_IN (DI)
unnamed: U$93.D_OUT (DO), U$94.D_IN (DI)
unnamed: U$93.CL_OUT (CO), U$94.C_IN (CI)
unnamed: U$94.D_OUT (DO), U$95.D_IN (DI)
unnamed: U$94.CL_OUT (CO), U$95.C_IN (CI)
unnamed: U$95.D_OUT (DO), U$96.D_IN (DI)
unnamed: U$95.CL_OUT (CO), U$96.C_IN (CI)
unnamed: U$96.D_OUT (DO), U$97.D_IN (DI)
unnamed: U$96.CL_OUT (CO), U$97.C_IN (CI)
unnamed: U$97.D_OUT (DO), U$98.D_IN (DI)
unnamed: U$97.CL_OUT (CO), U$98.C_IN (CI)
unnamed: U$99.D_OUT (DO), U$100.D_IN (DI)
unnamed: U$99.CL_OUT (CO), U$100.C_IN (CI)
unnamed: U$100.D_OUT (DO), U$101.D_IN (DI)
unnamed: U$100.CL_OUT (CO), U$101.C_IN (CI)
unnamed: U$101.D_OUT (DO), U$102.D_IN (DI)
unnamed: U$101.CL_OUT (CO), U$102.C_IN (CI)
unnamed: U$102.D_OUT (DO), U$103.D_IN (DI)
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

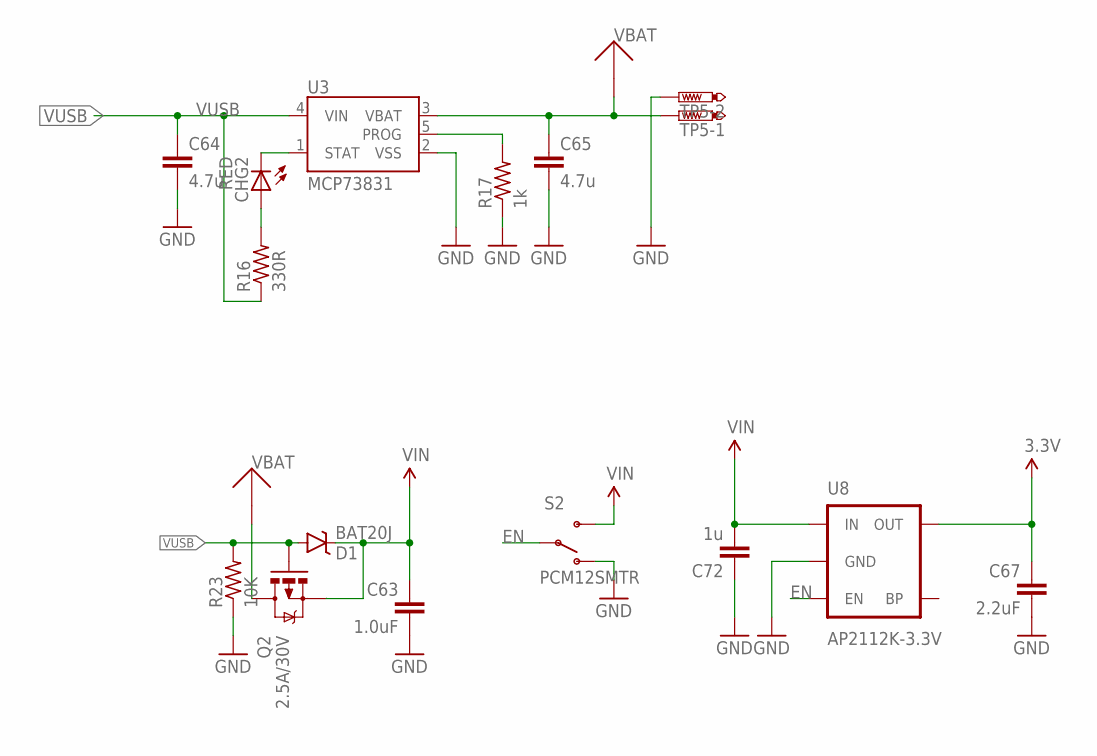
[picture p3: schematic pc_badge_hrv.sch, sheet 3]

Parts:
C63: 1.0uF; C0402
C64, C65: 4.7u; C0805
C67: 2.2uF; C0402
C72: 1u; C0402
CHG2: RED; CHIPLED_0603
D1: BAT20J; SOD-323
Q2: 2.5A/30V; SOT23-3
R16: 330R; R0402
R17: 1k; R0402
R23: 10K; R0402
S2: PCM12SMTR; SWITCH-SPST-SMD-A
TP5: PTR2; P2-38-17
U3: MCP73831; SOT23-5
U8: AP2112K-3.3V; SOT23-5

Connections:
3.3V: C67.1, U8.5 (OUT); also elsewhere on the board
EN: S2.2, U8.3 (EN)
GND: C63.2, C64.2, C65.2, C67.2, C72.1, R17.1, R23.1, S2.1 (O), TP5.TP-2, U3.2 (VSS), U8.2 (GND); also elsewhere on the board
unnamed: CHG2.C, U3.1 (STAT)
unnamed: CHG2.A, R16.2
unnamed: R17.2, U3.5 (PROG)
VBAT: C65.1, Q2.3 (D), TP5.TP-1, U3.3 (VBAT); also elsewhere on the board
VIN: C63.1, C72.2, D1.C, Q2.2 (S), S2.3 (S), U8.1 (IN); also elsewhere on the board
VUSB: C64.1, D1.A, Q2.1 (G), R16.1, R23.2, U3.4 (VIN); also elsewhere on the board

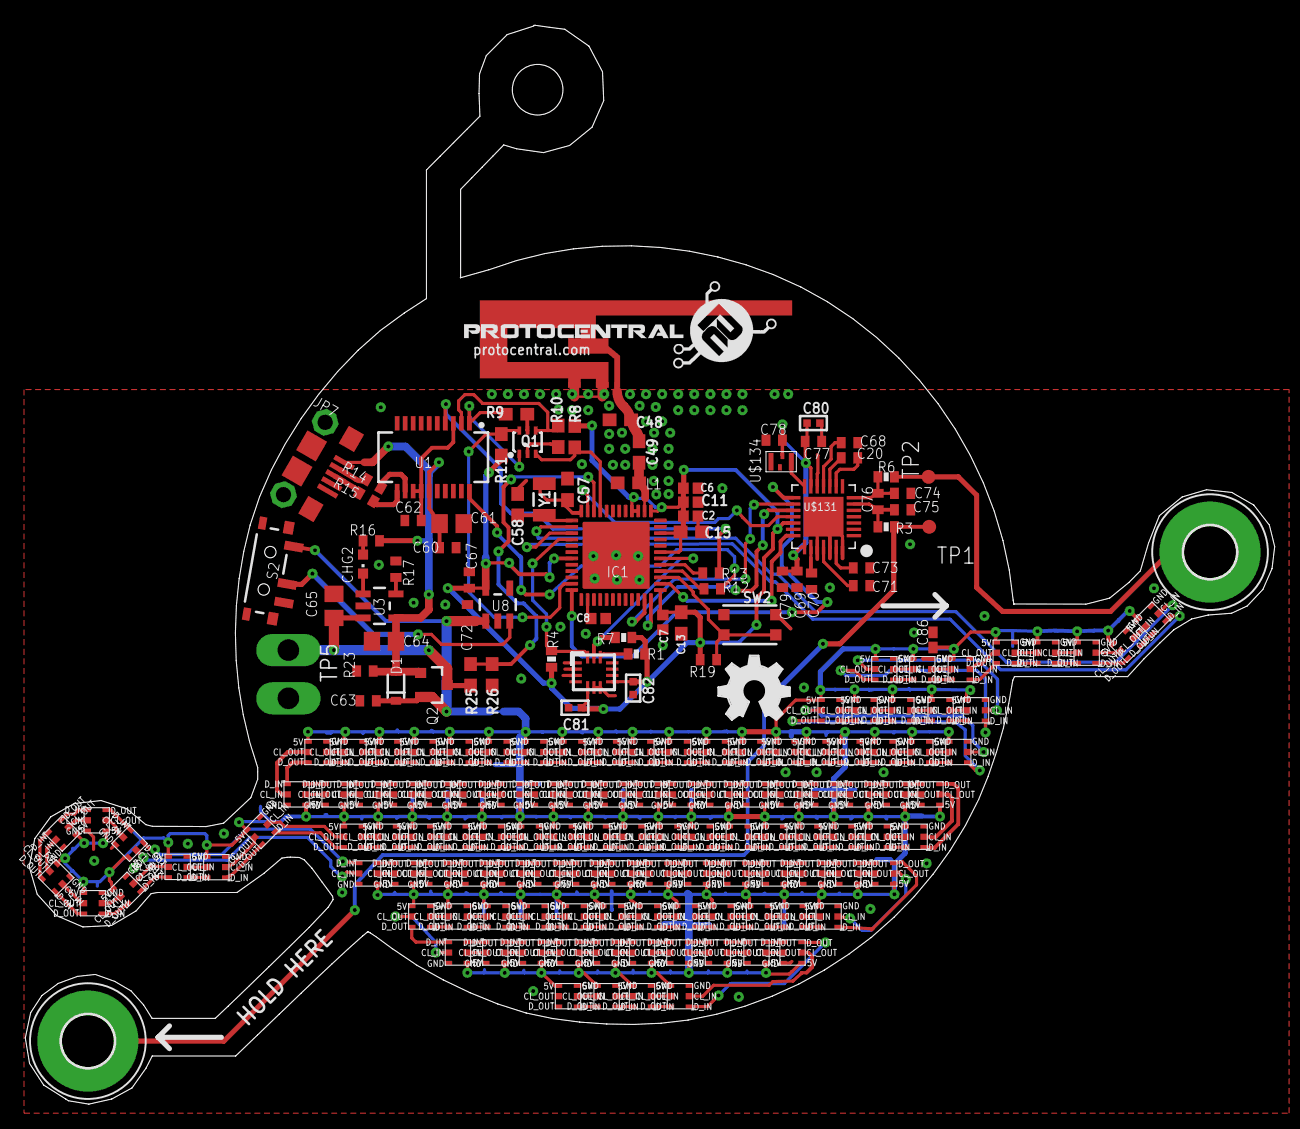
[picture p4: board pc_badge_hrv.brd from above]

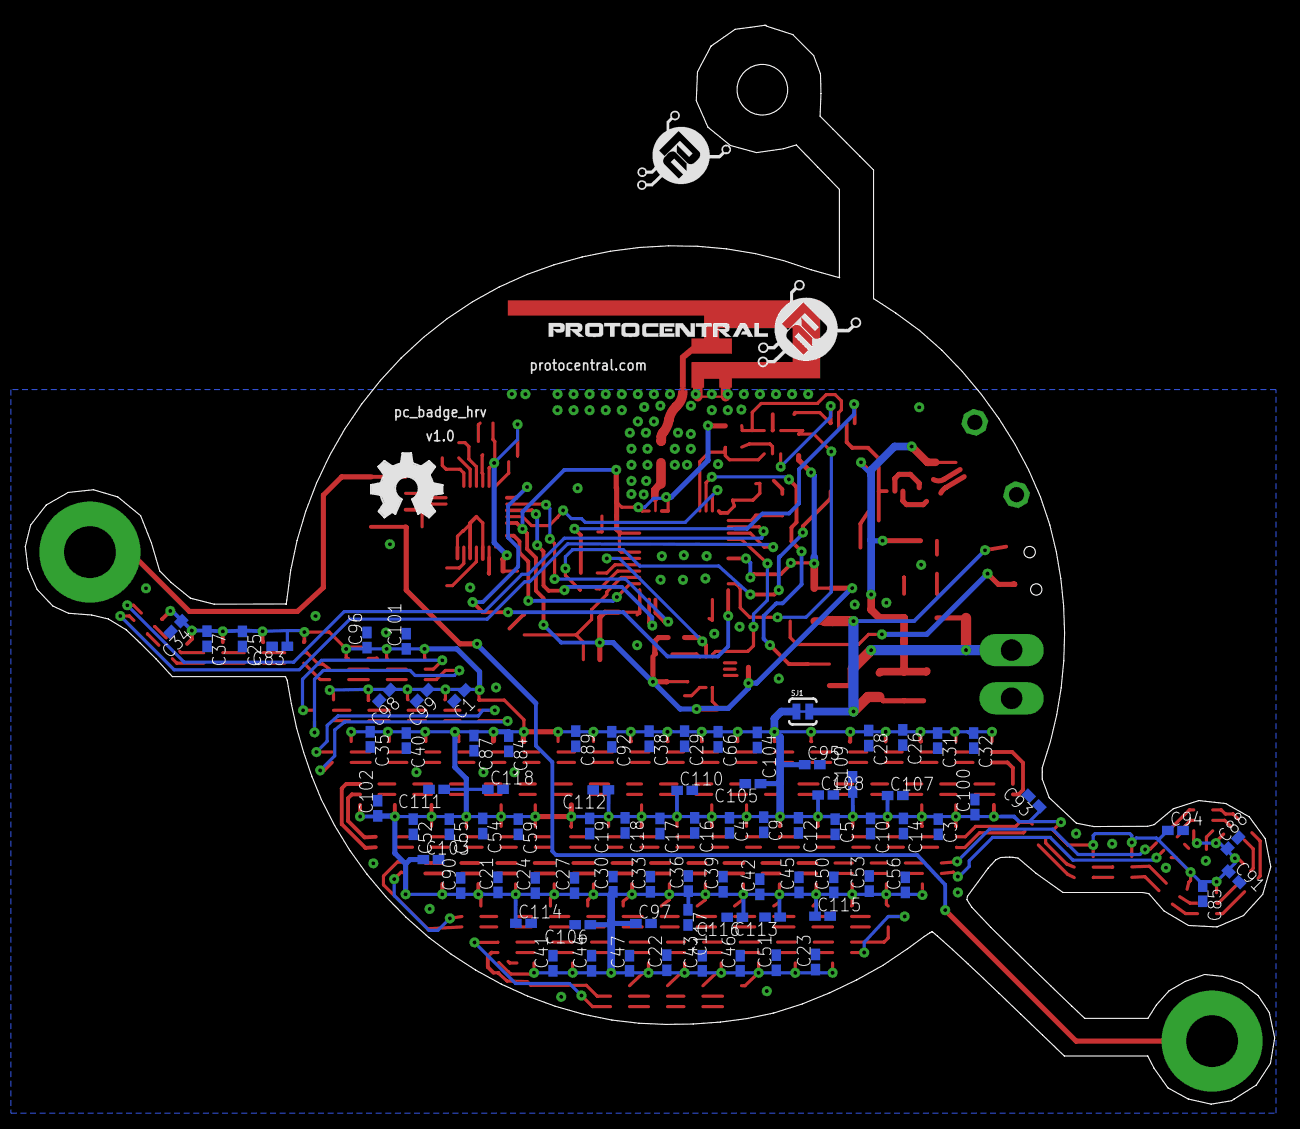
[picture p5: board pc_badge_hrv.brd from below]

Board: 4 copper layers, 98.8 x 85.3 mm, 283 parts (87 on the bottom side), 288 nets.

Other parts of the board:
LOGO2: OSHW_LOGO_FILLX0200-NT; OSHW_FILLX200_NOTEXT
U$1, U$26: PROTY_LOGO_WITH_TEXT; PROTY_WITH_TEXT@1
U$6: LOGO-PROTY

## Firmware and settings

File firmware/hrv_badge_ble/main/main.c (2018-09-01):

#include <stdio.h>
#include <stdlib.h>
#include <string.h>
#include <sys/socket.h>

#include "freertos/FreeRTOS.h"
#include "freertos/task.h"
#include "freertos/event_groups.h"
#include "esp_system.h"
#include "esp_event.h"
#include "esp_event_loop.h"
#include "nvs_flash.h"
#include "driver/gpio.h"
#include "driver/spi_master.h"
#include "driver/ledc.h"
#include "driver/i2c.h"
#include "driver/uart.h"
#include "driver/sdmmc_host.h"

#include "esp_log.h"
#include "max30003.h"
#include "ble.h"
#include "hpadc.h"
#include "protocentral_apa102.h"


#define TAG "HRV-BADGE"
#define delay_ms(ms) vTaskDelay((ms) / portTICK_RATE_MS)
#define KALAM32_MDNS_ENABLED    FALSE
#define KALAM32_MDNS_NAME       "heartypatch"
#define BUF_SIZE  1000

extern QueueHandle_t xQueue_tcp;
extern xSemaphoreHandle print_mux;

unsigned int global_heartRate ; 


void app_main(void)
{

	esp_err_t ret;
    ret = nvs_flash_init();
    if (ret == ESP_ERR_NVS_NO_FREE_PAGES) {
        ESP_ERROR_CHECK(nvs_flash_erase());
        ret = nvs_flash_init();
    }
    ESP_ERROR_CHECK( ret );
	
	xQueue_tcp = xQueueCreate(20, sizeof( struct Tcp_Message *));
	if( xQueue_tcp==NULL )
	{
		ESP_LOGI(TAG, "Failed to create Queue..!");
	}
	
    init_apa102_spi();
    blink_apa102();
    
    max30003_initchip(PIN_SPI_MISO,PIN_SPI_MOSI,PIN_SPI_SCK,PIN_SPI_CS);

    kalam_start_max30003();
    kalam32_adc_start();

	vTaskDelay(2000/ portTICK_PERIOD_MS);		//give sometime for max to settle

#ifdef CONFIG_BLE_MODE_ENABLE
	kalam_ble_Init();		
#endif
    while(true){

        vTaskDelay(10/ portTICK_PERIOD_MS);   
    }
	
}

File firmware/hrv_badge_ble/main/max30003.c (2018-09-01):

#include <stdio.h>
#include <stdlib.h>
#include<math.h>
#include <string.h>
#include "freertos/FreeRTOS.h"
#include "esp_wifi.h"
#include "esp_system.h"
#include "esp_event.h"
#include "esp_event_loop.h"
#include "nvs_flash.h"
#include "driver/gpio.h"
#include "driver/spi_master.h"
#include "bt.h"
#include "driver/ledc.h"
#include "driver/uart.h"

#include "max30003.h"
#include "ble.h"
#include "protocentral_apa102.h"

uint8_t SPI_TX_Buff[4];
uint8_t SPI_RX_Buff[10];
uint8_t DataPacketHeader[20];

signed long ecgdata;
unsigned long data;
char SPI_temp_32b[4];
int flag;
unsigned long ps;

spi_device_handle_t spi;
uint8_t rtor_detected  =0;
static xQueueHandle max30003intSem;
SemaphoreHandle_t updateRRSemaphore = NULL;
extern unsigned int global_heartRate ;

unsigned int array[MAX] = {0};
int rear = -1;
int i ;
float rmssd;
float mean_f;
float rmssd_f;
int count = 0;
float per_pnn;
int sqsum;
int hist[] = {0};
float sdnn;
float sdnn_f;
int k=0;
int min_f=0;
int max_f=0;
int max_t=0;
int min_t=0;
float pnn_f=0;
float tri =0;


void max30003_spi_pre_transfer_callback(spi_transaction_t *t)
{
}

void IRAM_ATTR gpio_isr_handler(void* arg)
{
  BaseType_t mustYield=false;
  xSemaphoreGiveFromISR(max30003intSem, &mustYield);

}

void max30003_start_timer(void)
{
  ledc_timer_config_t ledc_timer =
  {
      .bit_num = LEDC_TIMER_10_BIT, //set timer counter bit number
      .freq_hz = 32768 ,             //set frequency of pwm
      .speed_mode = LEDC_HIGH_SPEED_MODE,   //timer mode,
      .timer_num = 0    //timer index
    };

    ledc_timer_config(&ledc_timer);

    ledc_channel_config_t ledc_channel =
    {
      .channel = LEDC_CHANNEL_0,
      .duty = 512,
      .gpio_num = PIN_NUM_FCLK,
      .intr_type = LEDC_INTR_DISABLE,
      .speed_mode = LEDC_HIGH_SPEED_MODE,
      .timer_sel = LEDC_TIMER_0
    };

    ledc_channel_config(&ledc_channel);
  }


void MAX30003_Reg_Write (unsigned char WRITE_ADDRESS, unsigned long data)
{
  uint8_t wRegName = (WRITE_ADDRESS<<1) | WREG;

  uint8_t txData[4];

  txData[0]=wRegName;
  txData[1]=(data>>16);
  txData[2]=(data>>8);
  txData[3]=(data);

  esp_err_t ret;
  spi_transaction_t t;

  memset(&t, 0, sizeof(t));       //Zero out the transaction

  t.length=32;                 //Len is in bytes, transaction length is in bits.
  t.tx_buffer=&txData;               //Data
  ret=spi_device_transmit(spi, &t);  //Transmit!
  assert(ret==ESP_OK);            //Should have had no issues.
}


void MAX30003_ReadID(void)
{
  uint8_t SPI_TX_Buff[4];
  uint8_t SPI_RX_Buff[10];

  uint8_t Reg_address=INFO;

  SPI_TX_Buff[0] = (Reg_address<<1 ) | RREG;
  SPI_TX_Buff[1]=0x00;
  SPI_TX_Buff[2]=0x00;
  SPI_TX_Buff[3]=0x00;

  esp_err_t ret;
  spi_transaction_t t;
   memset(&t, 0, sizeof(t));       //Zero out the transaction

   t.length=32;                     //Command is 8 bits
   t.rxlength=32;
   t.tx_buffer=&SPI_TX_Buff;               //The data is the cmd itself
   t.rx_buffer=&SPI_RX_Buff;

   t.user=(void*)0;                //D/C needs to be set to 0
   ret=spi_device_transmit(spi, &t);  //Transmit!
   assert(ret==ESP_OK);            //Should have had no issues.
 }

void max30003_reg_read(unsigned char WRITE_ADDRESS)
{
  uint8_t Reg_address=WRITE_ADDRESS;

  SPI_TX_Buff[0] = (Reg_address<<1 ) | RREG;
  SPI_TX_Buff[1]=0x00;
  SPI_TX_Buff[2]=0x00;
  SPI_TX_Buff[3]=0x00;

  esp_err_t ret;
  spi_transaction_t t;
  memset(&t, 0, sizeof(t));       //Zero out the transaction

  t.length=32;
  t.rxlength=32;
  t.tx_buffer=&SPI_TX_Buff;
  t.rx_buffer=&SPI_RX_Buff;

  t.user=(void*)0;
  ret=spi_device_transmit(spi, &t);
  assert(ret==ESP_OK);            //Should have had no issues.

  SPI_temp_32b[0] = SPI_RX_Buff[1];
  SPI_temp_32b[1] = SPI_RX_Buff[2];
  SPI_temp_32b[2] = SPI_RX_Buff[3];

}

void read_data(void *pvParameters)			// calls max30003read_data to update to aws_iot.
{

   while(1)
    {
		 xSemaphoreTake(max30003intSem,  portMAX_DELAY);//Wait until slave is ready
	   
		 max30003_read_send_data();
		 xSemaphoreGive(updateRRSemaphore);
	   vTaskDelay(10/portTICK_RATE_MS);
    }
}

void max30003_sw_reset(void)
{
  MAX30003_Reg_Write(SW_RST,0x000000);
  vTaskDelay(100 / portTICK_PERIOD_MS);
}

void max30003_synch(void)
{
  MAX30003_Reg_Write(SYNCH,0x000000);
}

void max30003_drdy_interrupt_enable() // DRDY isr
{
  gpio_config_t io_conf;
  io_conf.intr_type = GPIO_PIN_INTR_POSEDGE;
  io_conf.pin_bit_mask = 1 << MAX30003_INT_PIN;
  io_conf.mode = GPIO_MODE_INPUT;
  gpio_config(&io_conf);

  gpio_set_intr_type(MAX30003_INT_PIN, GPIO_PIN_INTR_POSEDGE);

  gpio_install_isr_service(0);
  gpio_isr_handler_remove(MAX30003_INT_PIN);
  gpio_isr_handler_add(MAX30003_INT_PIN, gpio_isr_handler, (void*) MAX30003_INT_PIN);
}

void max30003_initchip(int pin_miso, int pin_mosi, int pin_sck, int pin_cs )
{

  esp_err_t ret;

  spi_bus_config_t buscfg=
  {
      .miso_io_num=pin_miso,
      .mosi_io_num=pin_mosi,
      .sclk_io_num=pin_sck,
      .quadwp_io_num=-1,
      .quadhd_io_num=-1
  };

  spi_device_interface_config_t devcfg=
  {
      .clock_speed_hz=4000000,             	
      .mode=0,                               	
      .spics_io_num=pin_cs,              		
      .queue_size=7,                          
      .pre_cb=max30003_spi_pre_transfer_callback,  
  };
  //Initialize the SPI bus
  ret=spi_bus_initialize(HSPI_HOST, &buscfg, 0);					//use 1 to enable DMA, should use idf version 3.0/2.0
  assert(ret==ESP_OK);
  //Attach the LCD to the SPI bus
  ret=spi_bus_add_device(HSPI_HOST, &devcfg, &spi);
  assert(ret==ESP_OK);
  max30003_start_timer();
  vTaskDelay(100 / portTICK_PERIOD_MS);

  max30003_sw_reset();
  vTaskDelay(100 / portTICK_PERIOD_MS);

  MAX30003_Reg_Write(CNFG_GEN, 0x080004);
  vTaskDelay(100 / portTICK_PERIOD_MS);

  MAX30003_Reg_Write(CNFG_CAL, 0x720000);  // 0x700000
  vTaskDelay(100 / portTICK_PERIOD_MS);

  MAX30003_Reg_Write(CNFG_EMUX,0x0B0000);
  vTaskDelay(100 / portTICK_PERIOD_MS);

  MAX30003_Reg_Write(CNFG_ECG, 0x005000);  // d23 - d22 : 10 for 250sps , 00:500 sps
  vTaskDelay(100 / portTICK_PERIOD_MS);

  MAX30003_Reg_Write(CNFG_RTOR1,0x3fc600);
  vTaskDelay(100 / portTICK_PERIOD_MS);

  MAX30003_Reg_Write(MNGR_INT, 0x000024);  //MAX30003_Reg_Write(MNGR_INT, 0x000014);
  vTaskDelay(100 / portTICK_PERIOD_MS);

  MAX30003_Reg_Write(EN_INT,0x000401);
  vTaskDelay(100 / portTICK_PERIOD_MS);

  max30003_synch();

  max30003_drdy_interrupt_enable();
}
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

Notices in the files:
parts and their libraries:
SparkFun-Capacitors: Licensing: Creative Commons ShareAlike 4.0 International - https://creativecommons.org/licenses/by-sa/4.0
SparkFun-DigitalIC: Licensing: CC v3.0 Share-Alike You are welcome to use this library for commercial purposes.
